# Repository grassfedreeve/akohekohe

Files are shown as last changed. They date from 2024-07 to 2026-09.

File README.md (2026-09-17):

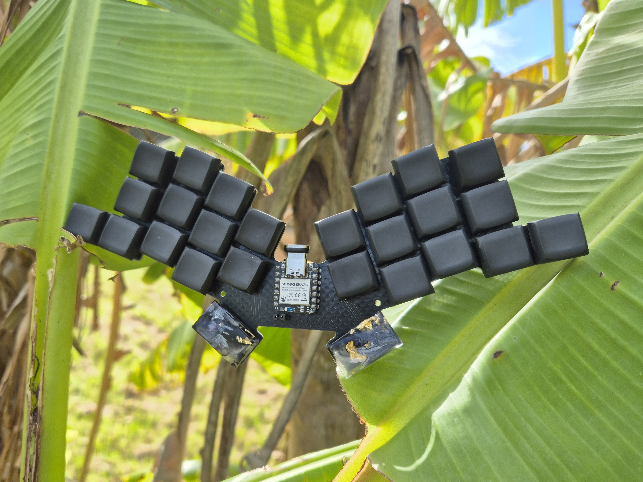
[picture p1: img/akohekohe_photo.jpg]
ʻākohekohe


# ʻākohekohe
26-key, column-staggered, unibody-split keyboard made with [ergogen](https://github.com/ergogen/ergogen) and [KiCad](https://www.kicad.org/). Named after the [ʻākohekohe bird](https://www.mauiforestbirds.org/akohekohe/), (“AH-kohay-kohay”), consider donating to the Maui Forest Bird Recovery Project. 

Basically a ZilpZalp with thumbs cut off, and the most comfortable layout I have found. 

Two versions for choc switches are available:
- The default-spacing solder-only version with silkscreen art and the [original without art](https://github.com/grassfedreeve/akohekohe/blob/main/pcb/gerbers-original.zip) (in the [pcb](https://github.com/grassfedreeve/akohekohe/tree/main/pcb) directory)
- The minimal-choc-spacing solder-only version with the tightest spacing that choc V1 switches allow for (in the [pcb_min_choc](https://github.com/grassfedreeve/akohekohe/tree/main/pcb_min_choc) directory)
  **Note:** You will have to procure min-spacing keycaps. I am not aware of any commercial solution. Recommendation: [Philadelphia Minimalist](https://github.com/pseudoku/PseudoMakeMeKeyCapProfiles/blob/master/Philadelphia_Minimalist.scad) by [Pseudoku](https://github.com/pseudoku). There are also currently no 1.5u min-space keycaps, these will need to be generated.

**Warning:** The min-choc-spacing version has not been tested yet!

# Keymap
Example keymap for how you might use this many keys, created using caksoylar's great [keymap-drawer](https://github.com/caksoylar/keymap-drawer)
keymap
Alternative base layouts, Colemak DH, [Bird](https://github.com/jcmkk3/bird-layout), and a Gallium mod shared to me by [ssbb](https://github.com/ssbb) are also great options:
altbase

## BOM
- 1 pcb
- 1 Seeed XIAO compatible controller
- 26 sod123 diodes
- 26 kailh choc low profile switches
- 26 keycaps

wireless parts (optional)
- [45mAh 351020 battery](https://www.ebay.com.au/itm/175319348479)
- [5mm pogo pin](https://www.aliexpress.com/item/1005006095992803.html?spm=a2g0o.order_list.order_list_main.35.78fd1802qp0XdF)
- [jumper](https://www.aliexpress.com/item/32827199777.html?spm=a2g0o.order_list.order_list_main.30.78fd1802qp0XdF)
## Firmware
ZMK is what I use and have setup a module for: [ākohekohe ZMK Module](https://github.com/grassfedreeve/zmk-keyboards-akohekohe) 
That being said the matrix is the same as a Hummingbird so you can use hummingbird firmware just fine on whichever firmware you enjoy.

## Art
perce came in and saved the day with amazing art for my keyboards, some quick photos of this are below:

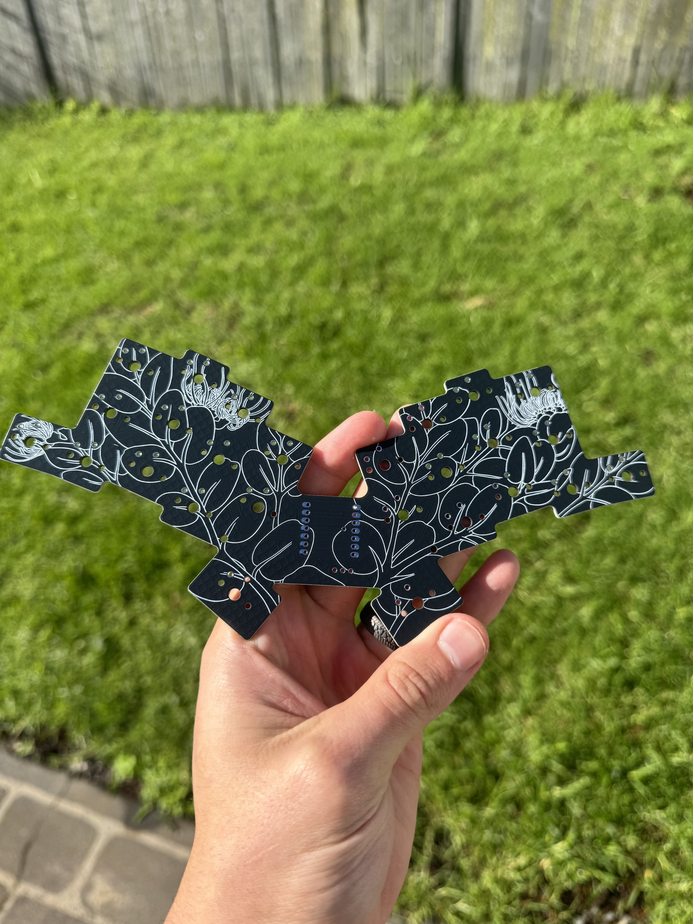
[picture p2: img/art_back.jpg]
back


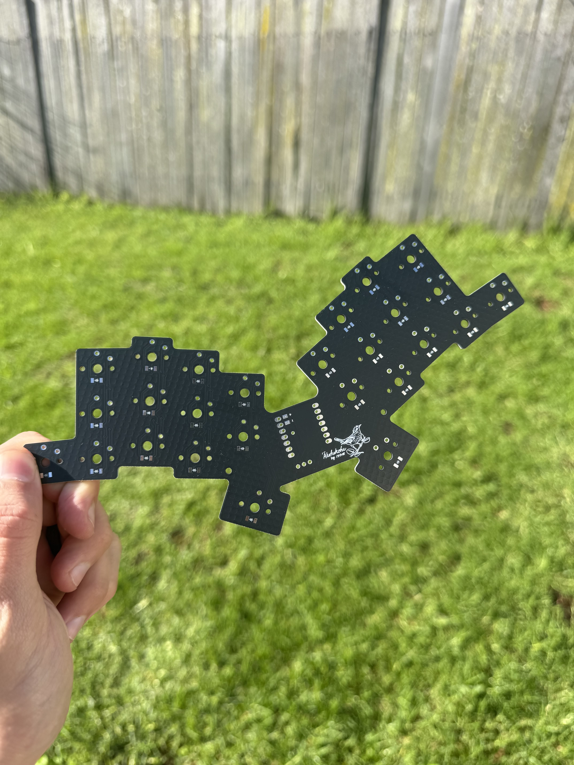
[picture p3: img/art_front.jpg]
front


## Inspiration & Thanks
- perce for making the stunning artwork | [madebyperce](https://madebyperce.com/) | [kofi](https://ko-fi.com/madebyperce)
- jcmkk3's [rufous](https://github.com/jcmkk3/trochilidae#rufous) hummingbird variation. Of which I used the Ergogen config, routing, and footprints.
- apfel's [zilpzalp](https://github.com/kilipan/zilpzalp) keyboard
- PJE66's [hummingbird](https://github.com/PJE66/hummingbird) keyboard
- Weteor's [grumpy](https://github.com/weteor/Grumpy) and [fitis](https://github.com/weteor/fitis)
- apsu's [aptmak](https://github.com/apsu/aptmak) keyboard layout

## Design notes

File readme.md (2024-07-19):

ʻākohekohe)

# ʻākohekohe
26-key, column-staggered, unibody-split keyboard made with [ergogen](https://github.com/ergogen/ergogen) and [KiCad](https://www.kicad.org/). Named after the [ʻākohekohe bird](https://www.mauiforestbirds.org/akohekohe/), consider donating to the Maui Forest Bird Recovery Project. 

Basically a ZilpZalp with thumbs cut off, and the most comfortable layout I have found. 

# Keymap
Example keymap for how you might use this many keys:
keymap

## BOM
- 1 pcb
- 1 Seeed XIAO compatible controller
- 26 sot23 diodes
- 26 kailh choc low profile switches
- 26 keycaps

## Firmware
ZMK is what I use and have setup a shield for. Though the matrix is the same as a Hummingbird so you can use hummingbird firmware just fine.

## Inspiration & Thanks
- jcmkk3's [rufous](https://github.com/jcmkk3/trochilidae#rufous) hummingbird variation. Of which I used the Ergogen config, routing, and footprints.
- apfel's [ZilpZalp](https://github.com/kilipan/zilpzalp) keyboard
- PJE66's [hummingbird](https://github.com/PJE66/hummingbird) keyboard
- Weteor' [grumpy](https://github.com/weteor/Grumpy) and [fitis](https://github.com/weteor/fitis)
- apsu's [aptmak](https://github.com/apsu/aptmak) keyboard layout

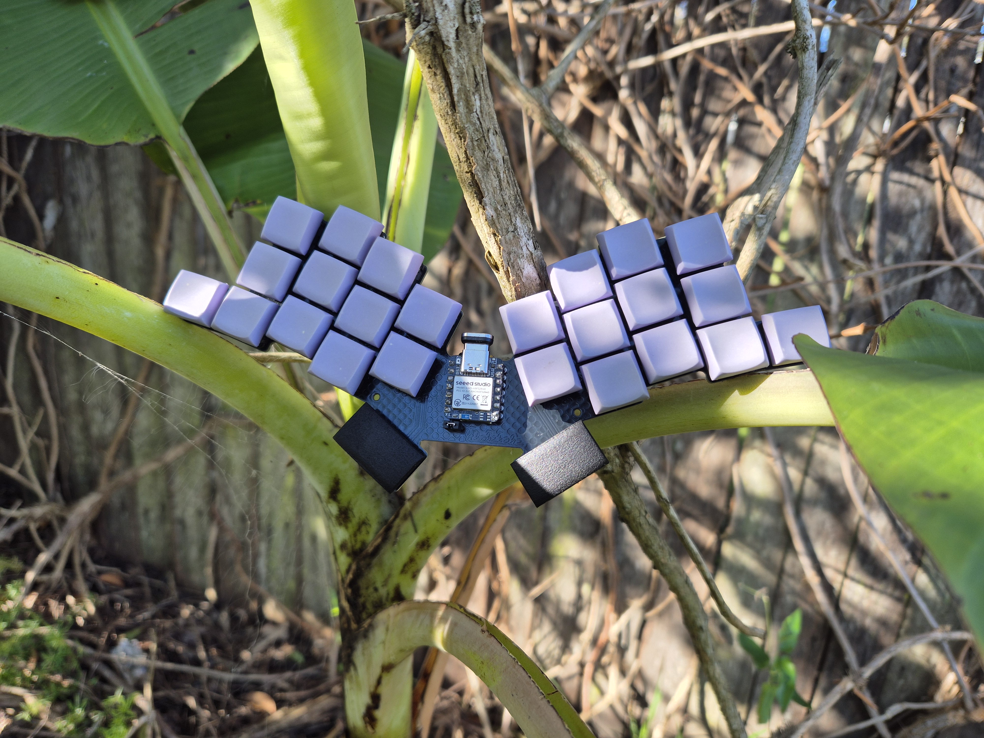
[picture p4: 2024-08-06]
img/akohekohe_photo_2.jpg

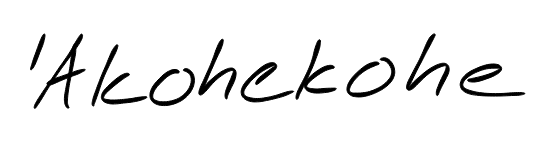
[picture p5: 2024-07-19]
pcb_min_choc/'Akohekohe_text.png

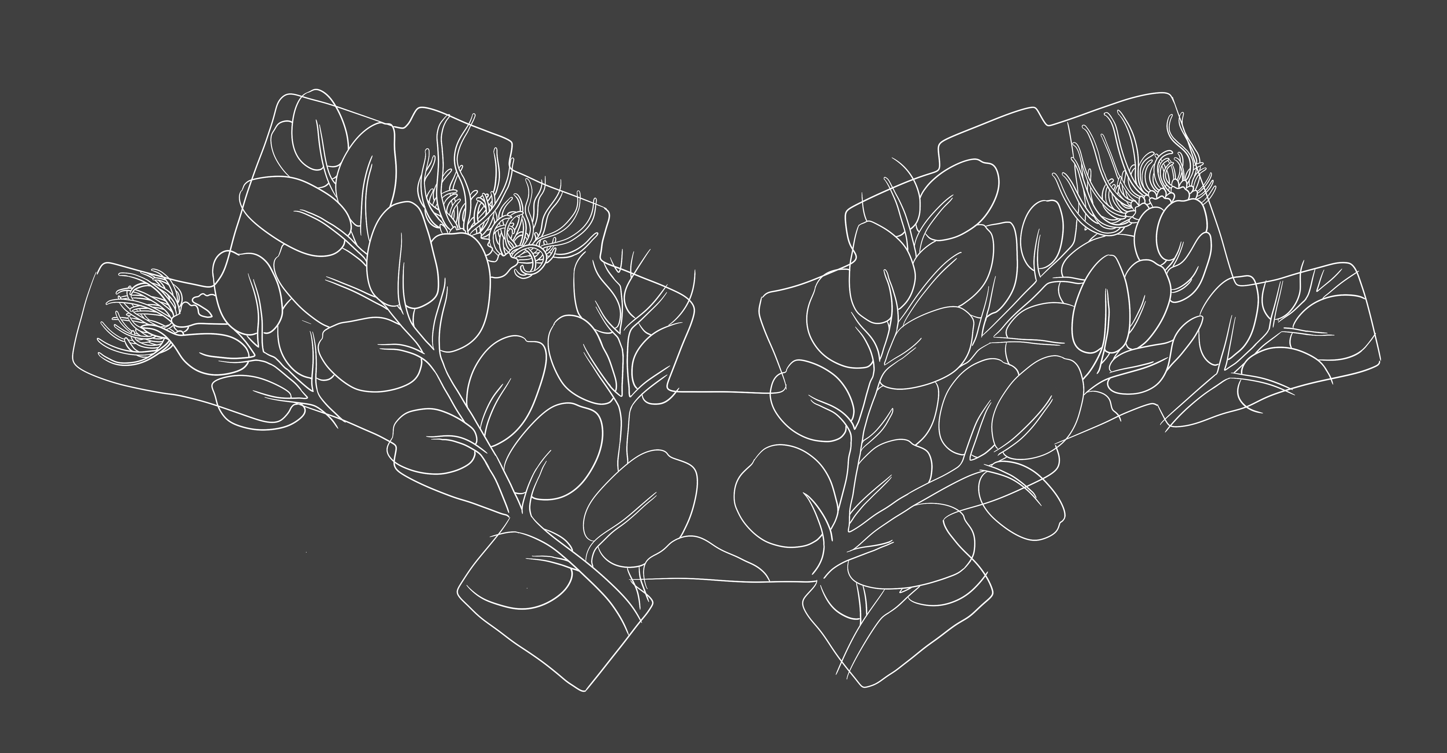
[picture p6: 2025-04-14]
pcb/akohekohe_back.png

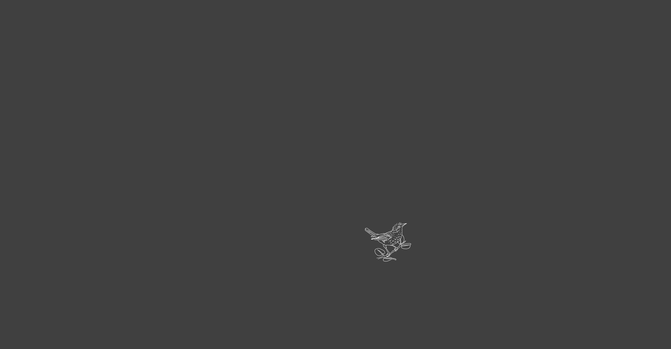
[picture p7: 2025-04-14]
pcb/akohekohe_front.png

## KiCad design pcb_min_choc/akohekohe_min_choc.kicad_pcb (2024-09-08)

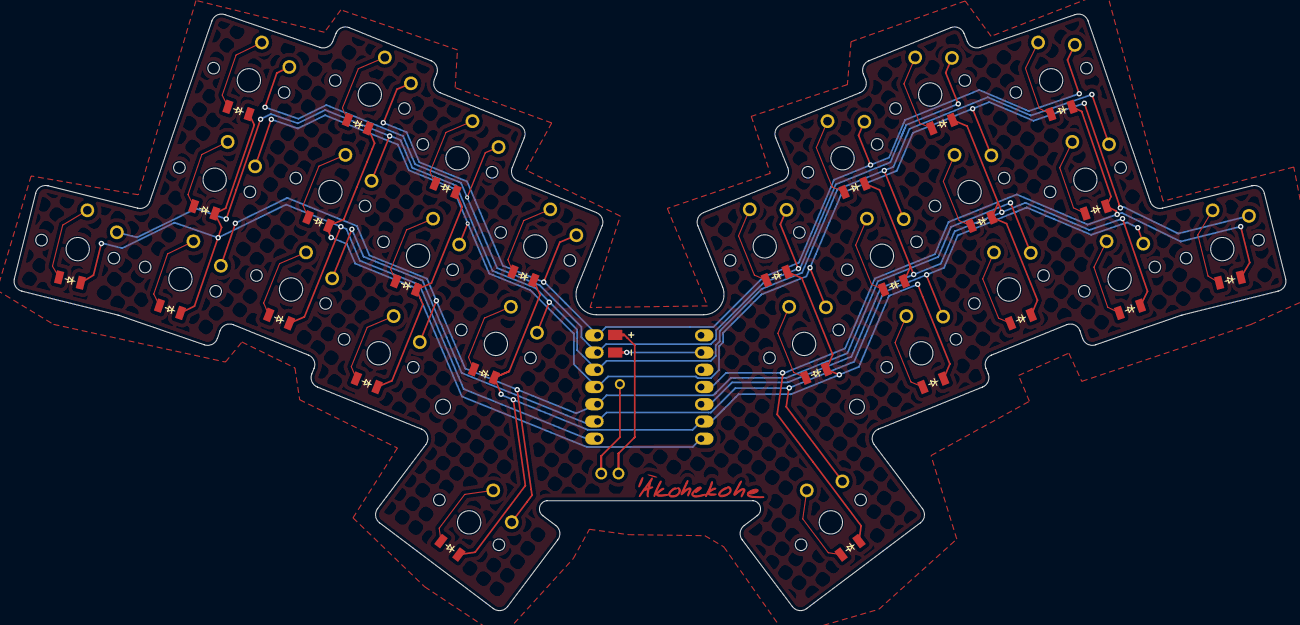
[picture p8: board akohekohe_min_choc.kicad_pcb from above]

Board: 2 copper layers, 187.5 x 87.9 mm, 31 parts (0 on the bottom side), 12 nets.

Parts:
BT1: Battery_Cell; BatteryPadsReversible
D9: Val**; HeaderJumperSimple
PAD1, PAD1#2: MountingHole_2.2mm_M2
S1, S2, S3, S4, S5, S6, S7, S8, S9, S10, S11, S12, S13, S14, S15, S16, S17, S18, S19, S20, S21, S22, S23, S24, S25, S26: ChocSimpleDiode
U1: xiao; xiao-tht

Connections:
GND: BT1.2, U1.13 (GND)
P0: S7.1, S12.1, S16.1, S22.1, U1.1 (A2)
P1: S4.1, S10.1, S19.1, S24.1, U1.2 (A4)
P2: S1.1, S6.1, S11.1, S15.1, S21.1, U1.3 (A10)
P3: S3.1, S9.1, S13.1, S18.1, S23.1, U1.4 (A11)
P4: S2.1, S8.1, S17.1, S25.1, U1.5 (A8_SDA)
P5: S5.1, S14.1, S20.1, S26.1, U1.6 (A9_SCL)
P6: S1.2, S2.2, S3.2, S4.2, S5.2, U1.7 (B8_TX)
P7: S6.2, S7.2, S8.2, S9.2, S10.2, U1.8 (B9_RX)
P8: S11.2, S12.2, S20.2, S23.2, S24.2, S25.2, U1.9 (A7_SCK)
P9: S14.2, S17.2, S18.2, S19.2, S21.2, S22.2, U1.10 (A5_MISO)
P10: S13.2, S15.2, S16.2, S26.2, U1.11 (A6_MOSI)

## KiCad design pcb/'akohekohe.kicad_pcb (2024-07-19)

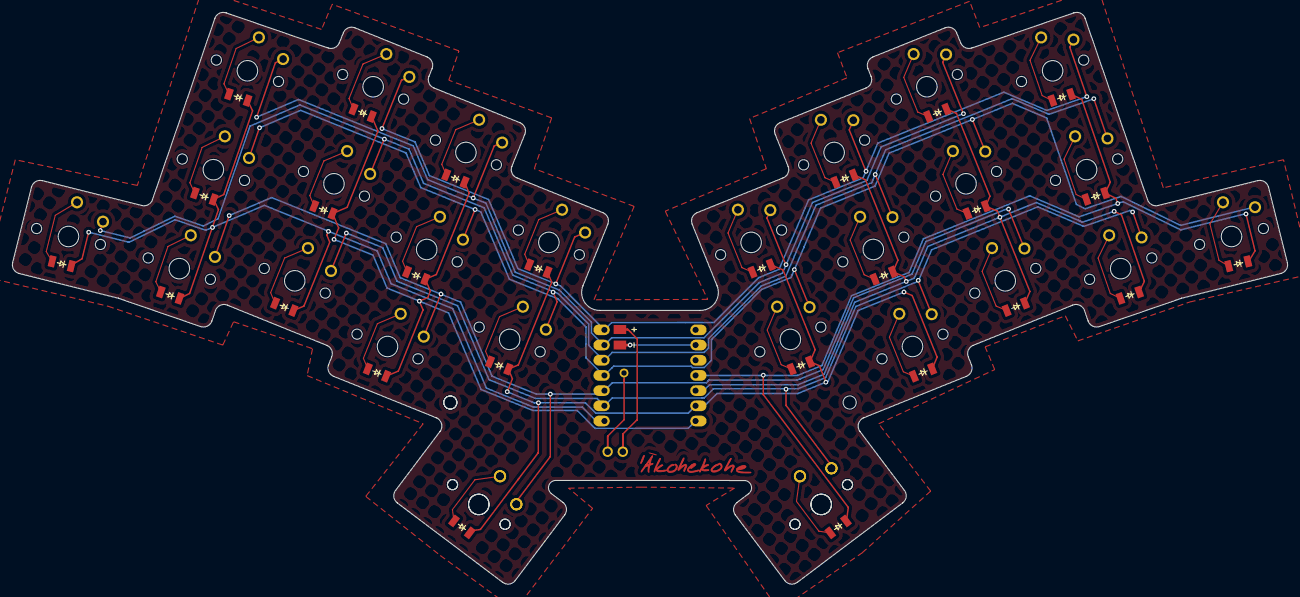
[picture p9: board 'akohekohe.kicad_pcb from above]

Board: 2 copper layers, 213.3 x 95.6 mm, 34 parts (0 on the bottom side), 12 nets.

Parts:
BT1: Battery_Cell; BatteryPadsReversible
D9: Val**; HeaderJumperSimple
PAD1, PAD1#2, PAD1#3: MountingHole_2.2mm_M2
S25, S26: PG1350
SW1, SW2, SW3, SW4, SW5, SW6, SW7, SW8, SW9, SW10, SW11, SW12, SW17, SW18, SW19, SW20, SW21, SW22, SW23, SW24, SW25, SW26, SW27, SW28: SW_Push; ChocSimpleDiode
SW14, SW15: SW_Push; ChocSimpleDiode 1.5u
U1: xiao; xiao-tht

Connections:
GND: BT1.2, U1.13 (GND)
P0: SW2.1, SW4.1, SW26.1, SW28.1, U1.1 (A2)
P1: SW1.1, SW3.1, SW25.1, SW27.1, U1.2 (A4)
P2: SW6.1, SW8.1, SW9.1, SW22.1, SW24.1, U1.3 (A10)
P3: SW5.1, SW7.1, SW20.1, SW21.1, SW23.1, U1.4 (A11)
P4: S25.1, SW10.1, SW12.1, SW14.1, SW18.1, U1.5 (A8_SDA)
P5: S26.1, SW11.1, SW15.1, SW17.1, SW19.1, U1.6 (A9_SCL)
P6: SW1.2, SW5.2, SW9.2, SW10.2, SW11.2, U1.7 (B8_TX)
P7: SW2.2, SW3.2, SW6.2, SW7.2, SW12.2, U1.8 (B9_RX)
P8: S25.2, SW4.2, SW8.2, SW14.2, SW17.2, SW21.2, SW25.2, U1.9 (A7_SCK)
P9: SW18.2, SW19.2, SW22.2, SW23.2, SW26.2, SW27.2, U1.10 (A5_MISO)
P10: S26.2, SW15.2, SW20.2, SW24.2, SW28.2, U1.11 (A6_MOSI)

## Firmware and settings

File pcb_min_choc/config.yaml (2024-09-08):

meta:
  engine: 4.0.0
  name: akohekohe-min
  version: 0.1
  author: grassfedreeve
  url: https://github.com/grassfedreeve/akohekohe

presets:
  # These presets provide different layout options
  # Select a preset in the `units` section below
  # Note: The appropriate switch footprint will still need to be set in the `pcb` section
  choc_spaced:
    capx: 17        # Key cap size horizontal
    capy: 16        # Key cap size vertical
    kx: 18.5        # Key spacing horizontal
    ky: 17.5        # Key spacing vertical
    pinky_splay: 5  # Degrees of splay between pinky and ring columns
    pinky_adj: -9   # Adjustment to compensate for splay spacing
    ring_splay: 3
    ring_adj: -8
    middle_splay: 0
    middle_adj: 0
    thumb_offsetx: 0.25kx
  
  choc_min_spaced:
    capx: 14.5
    capy: 14.5
    kx: 15.5
    ky: 15.5
    pinky_splay: 5
    pinky_adj: -3
    ring_splay: 3
    ring_adj: -8
    middle_splay: 3
    middle_adj: -5
    thumb_offsetx: 1/3kx

  mx_spaced:
    capx: 18
    capy: 18
    kx: 19
    ky: 19
    pinky_splay: 5
    pinky_adj: -4
    ring_splay: 3
    ring_adj: -10
    middle_splay: 0
    middle_adj: 0
    thumb_offsetx: 0.25kx
  
  mx_min_spaced:
    capx: 15.5
    capy: 15.5
    kx: 16 + 0.5
    ky: 16 + 0.5
    pinky_splay: 5
    pinky_adj: -3
    ring_splay: 3
    ring_adj: -8
    middle_splay: 3
    middle_adj: -5
    thumb_offsetx: 1/3kx

units:
  $extends: presets.choc_min_spaced
  angle: 22  # Angle between halves

  # Defaults/Constants
  # ====================
  $default_height: 0  # Points invisible by default unless height/width explicitly set
  $default_width: 0
  xiao_x: 17.8
  xiao_y: 21
  sf: 16

points:
  zones.matrix:
    anchor.shift: [100, -100]  # Fix placement on KiCAD sheet
    rotate: -angle + pinky_splay + ring_splay
    mirror:
      ref: matrix_inner_top
      shift: [0.5sf, 0.5sf]
      distance: 13
    key:
      width: capx
      height: capy
      spread: kx      
      padding: ky
      autobind: 0
    rows:
      bottom:
      home:
      top:
    columns.pinky:
      rows:
        bottom.skip: true
        top.skip: true
        home:
          bind: [0ky, 0.5kx, 0, 0]
          row_net: P2
          column_net: P6
        home.mirror:
          row_net: P3
          column_net: P10
    columns.ring:
      key:
        stagger: 0.96ky
        splay: -pinky_splay
        origin: [0, pinky_adj]
      rows:
        bottom:
          bind: [0.5ky, 0, 0, 0]
          row_net: P4
          column_net: P6
        home:
          bind: [0, 0.5kx, 0, 0]
          row_net: P3
          column_net: P6
        top:
          bind: [0, 0.5kx, 0.5ky, 0]
          row_net: P1
          column_net: P6
        bottom.mirror:
          row_net: P5
          column_net: P9
        home.mirror:
          row_net: P2
          column_net: P10
        top.mirror:
          row_net: P0
          column_net: P10
    columns.middle:
      key:
        stagger: 0.25ky
        splay: -ring_splay
        origin: [0, ring_adj]
      rows:
        bottom:
          bind: [0.5ky, 0.5kx, 0, 0.5kx]
          row_net: P5
          column_net: P6
        home:
          bind: [0, 0.5kx, 0, 0]
          row_net: P2
          column_net: P7
        top:
          bind: [0, 0, 0.5ky, 0]
          row_net: P0
          column_net: P7
        bottom.mirror:
          row_net: P4
          column_net: P9
        home.mirror:
          row_net: P3
          column_net: P9
        top.mirror:
          row_net: P1
          column_net: P9
    columns.index:
      key.stagger: -0.25ky
      rows:
        bottom:
          bind: [0.5ky, 0, 0, 0]
          row_net: P4
          column_net: P7
        home:
          row_net: P3
          column_net: P7
        top:
          bind: [0, 0, 0.5ky, 0.5kx]
          row_net: P1
          column_net: P7
        bottom.mirror:
          row_net: P5
          column_net: P8
        home.mirror:
          row_net: P2
          column_net: P9
        top.mirror:
          row_net: P0
          column_net: P9
    columns.inner:
      key.stagger: -0.5ky
      rows:
        bottom.skip: true
        home:
          bind: [0.5ky, 0, 0.5ky, 0.5kx]
          row_net: P2
          column_net: P8
        top:
          bind: [0, 0, 0.5ky, 0.5kx]
          row_net: P0
          column_net: P8
        home.mirror:
          row_net: P3
          column_net: P8
        top.mirror:
          row_net: P1
          column_net: P8
  zones.thumb:
    anchor:
      ref: matrix_index_bottom
      shift: [1.4kx, -13]
    mirror.$extends: points.zones.matrix.mirror
    key.$extends: points.zones.matrix.key
    columns:
      reachy:
        key:
          stagger: -0.33ky
          rotate: -15
          width: 1.5ky        
          bind: [1.5ky, 0, 0, 0]
          row_net: P4
          column_net: P8
        key.mirror:
          row_net: P5
          column_net: P10
  zones.reference_top_center:
    anchor:
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

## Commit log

2024-09-08 add choc-min pcb and update readme
    [akohekohe-B_Cu.gbr, akohekohe-B_Mask.gbr, akohekohe-B_Paste.gbr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]
2024-09-08 ran DRC and fixed minspace
    [akohekohe-B_Cu.gbr, akohekohe-B_Mask.gbr, akohekohe-Edge_Cuts.gbr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]
2025-04-14 silkscreen art <3 THANK YOU PERCE
    ['akohekohe-B_Cu.gbr, 'akohekohe-B_Mask.gbr, 'akohekohe-B_Paste.gbr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]
2025-04-18 final art & 3 pin
    ['akohekohe-B_Cu.gbr, 'akohekohe-B_Mask.gbr, 'akohekohe-B_Paste.gbr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]
